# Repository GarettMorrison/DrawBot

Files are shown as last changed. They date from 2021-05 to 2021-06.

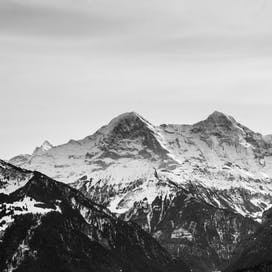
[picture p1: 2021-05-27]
DrawBoi_Dated/generateDrawfiles/Mountains.png

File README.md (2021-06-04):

### Code for large drawing robot

This is the WIP codebase for the DrawBot portion of my AI Art experiment. The target is to create an impressionist drawing of a target image on a canvas using procedural generation and robotics. 

Work in progress, SmallBoi.ino and controlSmallBoi.py have fully functional communication and can execute commands and scripts. DrawDXF.py converts dxf files to a list of commands readable by the controller script. 

SmallBoi is a simple stepper driven pulley system which, by controlling the length of two strings to a center mechanism, can move the head to any point on the surface. It also has a pair of servos on the head that can select one of four markers for printing. 

BigBoi consists of two DIY servos (referred to as bigServos) and a small hobby servo. Each bigServo is a DC motor driven by an L298N driver. It is connected via a gear (which gives a torque advantage) to a large spool, whos position is measured via potentiometer. These two spools connect to joints on a large (6ft tall) 2 axis arm, allowing control of the position of its head. The hobby servo control the pen on the head of the robot, by driving a spool which runs over pulleys, up through the arm, and around another spool which rotates the pen's angle. I used cheap DC motors, which are comically underpowered for the scale of the mechanism. I intend to add a pulley system to give ridiculously high mechanical advantage, which will be slow but able to draw without buying additional motors. 

Blog post in progress [here](https://www.garettmorrison.net/posts/in-progress/#drawbot)

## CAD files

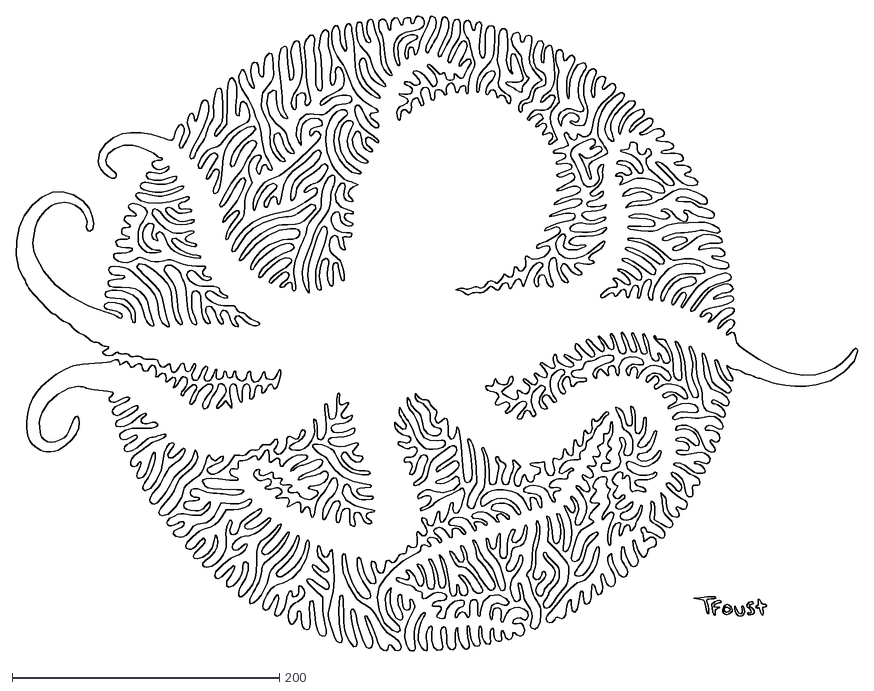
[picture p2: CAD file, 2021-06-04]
py/data/octopus.dxf
629.1 x 474.8

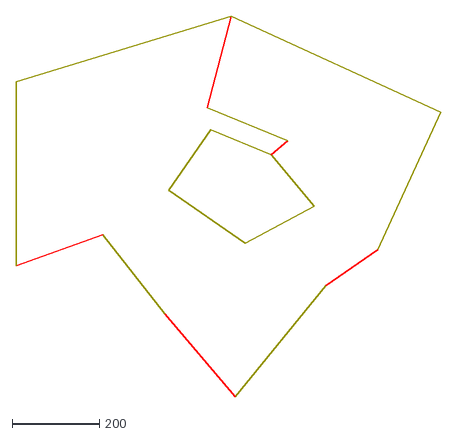
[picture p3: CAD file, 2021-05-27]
py/out/Drawing1.dxf
971.4 x 871.2

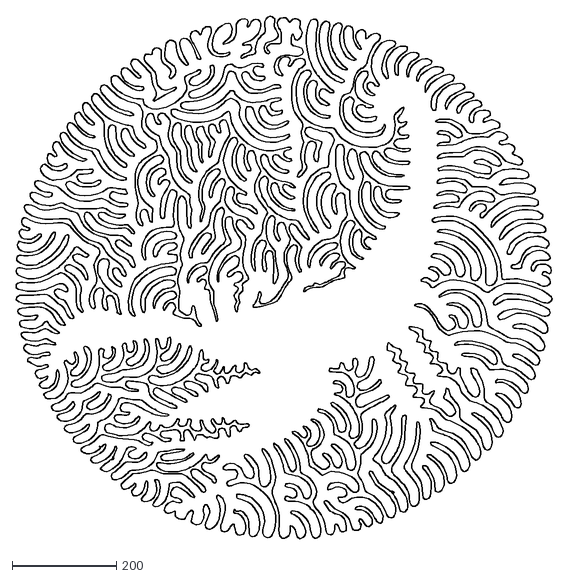
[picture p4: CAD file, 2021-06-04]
py/data/Scorp.dxf
1029.8 x 1003.4

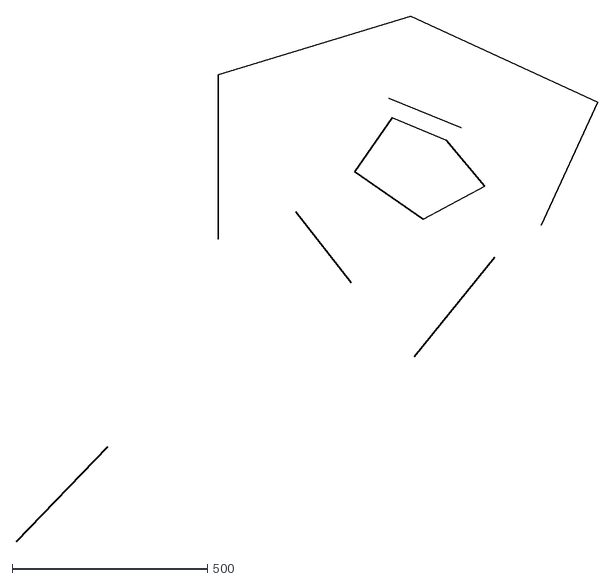
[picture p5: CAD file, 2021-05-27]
py/data/D1.dxf
1488.6 x 1344.6

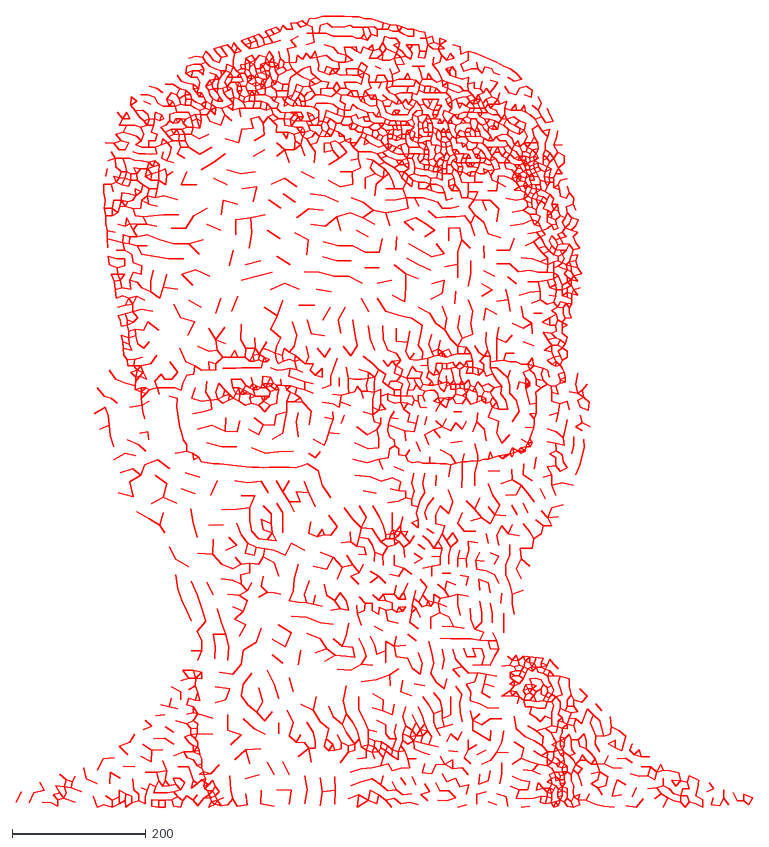
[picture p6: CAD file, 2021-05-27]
py/data/portrait.dxf
1103.0 x 1185.0

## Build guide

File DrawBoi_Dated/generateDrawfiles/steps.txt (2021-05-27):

0
0
0
0
0
0
0
0
0
0
0
0
0
0
0
0
0
0
0
0
0
0
0
0
0
0
0
0
0
0
0
0
0
0
0
0
0
0
0
0
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

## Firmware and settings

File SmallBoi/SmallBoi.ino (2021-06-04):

#include <Servo.h>
#include <math.h>
#include "miniStepper.h"

byte val; // variable to receive data from the serial port
int ledpin = 13; // Arduino LED pin 13 (on-board LED)

//Settings that can be changed in code, values are in 1/10"
int stepDelay = 7;
int stepDist = 52;
int lInit = 510;
int base = 455;
int lServoPos[] = {35, 135};  
int rServoPos[] = {125,45};
int imageScale = 60;
int lineXYDistStep = 20;
//Reference vals by pointer set
int *params[] = {&stepDelay, &stepDist, &lInit, &base, &lServoPos[0], &lServoPos[1], &rServoPos[0], &rServoPos[1], &imageScale, &lineXYDistStep};

float w0 = base/2;
float h0 = sqrt(pow(lInit, 2) - pow(base/2, 2));

byte command;
byte inBytes[10];

miniStepper left;
miniStepper right;

Servo lServo;
Servo rServo;


int twoByteInt(int MSB, int LSB){
   long int sum = (MSB*256 +LSB) -32767;
   if(sum > 32767){sum = 32767;}
   if(sum < -32767){sum = -32767;}
   return(sum);
}

float getDist(float x, float y){
   return(sqrt(pow(x, 2) + pow(y, 2)));
}

void getLR_fromXY(long int* outLR, float X, float Y){ //Converts XY raws into LR step positions
   float w = (X/32000)*imageScale + w0; //x position in dim + init width
   float h = (-1* Y/32000)*imageScale + h0; //y pos in dim + init h
   
   // Serial.println(X);
   // Serial.println(Y);
   // Serial.println('-');
   // Serial.println(w);
   // Serial.println(h);
   
   outLR[0] = floor((getDist(w      ,h) -lInit) *stepDist); //L position
   outLR[1] = floor((getDist(base -w,h) -lInit) *stepDist); //R position

   // Serial.println('-');
   // Serial.println(outLR[0]);
   // Serial.println(outLR[1]);
}

void getXY_fromLR(long int* outXY, float L, float R){
   float w = (pow(L/stepDist +lInit,2) - pow(R/stepDist +lInit,2) + pow(base,2)) / (2*base);
   float h = sqrt(pow(L/stepDist +lInit,2) - pow(w,2));

   outXY[0] = (w -w0) * (32000/imageScale);
   outXY[1] = (h -h0) * (32000/imageScale) *-1;

   // Serial.println('-');
   // Serial.println(w);
   // Serial.println(h);

   // Serial.println('-');
   // Serial.println(outXY[0]);
   // Serial.println(outXY[1]);
   // Serial.println("-----");
}

void moveR(int lTarget, int rTarget){
   bool doLoop = true;

   while(doLoop){
      int rPos = right.getPos();
      int lPos = left.getPos();

      if(lTarget == lPos && rTarget == rPos){
         doLoop = false;
         break;
      }

      if(lTarget < lPos){
         left.stepDown();
      }
      else if(lTarget > lPos){
         left.stepUp();
      }

      if(rTarget < rPos){
         right.stepDown();
      }
      else if(rTarget > rPos){
         right.stepUp();
      }

      delay(stepDelay);
   }
}



// void doLine(int xTarget, int yTarget){
//    //Get start of line from current pos
//    int startXY[2];
//    getXY_fromLR(startXY, left.getPos(), right.getPos());

//    //Calculated vals
//    int xDist = xTarget - startXY[0];
//    int yDist = yTarget - startXY[1];
//    float dist = getDist(xDist, yDist);
//    int pos = 0;

//    int targLR[2];

//    Serial.println("-");

//    Serial.print("Targs: ");
//    Serial.print(xTarget);
//    Serial.print(" | ");
//    Serial.println(yTarget);


//    Serial.print("StartPos: ");
//    Serial.print(startXY[0]);
//    Serial.print(" | ");
//    Serial.println(startXY[1]);



//    Serial.print("Dists: ");
//    Serial.print(dist);
//    Serial.print(" | ");
//    Serial.print(xDist);
//    Serial.print(" | ");
//    Serial.println(yDist);

//    while(true){
//       float frac = pos/dist;

//       //Break if after line
//       if(frac > 1){
//          break;
//       }

//       int xPos = frac*xDist +startXY[0];
//       int yPos = frac*yDist +startXY[1];

//       getLR_fromXY(targLR, xPos, yPos);

//       Serial.print(floor(frac*1000)); Serial.print(" | "); Serial.print(xPos); Serial.print(" | "); Serial.print(yPos);Serial.print(" | "); Serial.print(targLR[0]); Serial.print(" | "); Serial.println(targLR[1]);

//       moveR(targLR[0], targLR[1]); //Move to this pos



//       pos += lineXYDistStep; //Increment pos
//    }
// }



void setup() {
   Serial.begin(9600); // start serial communication at 9600bps

   left.attach(2,3,4,5);
   right.attach(7,8,11,12);

   lServo.attach(9);
   lServo.write(90);
   rServo.attach(10);
   rServo.write(90);

   pinMode(ledpin, OUTPUT); // pin 13 (on-board LED) as OUTPUT



   //---------------------------------------------------- Test functions

   // Serial.println("------");

   //    stepDelay = 1;
   //    int startXY[2];
   //    int targLR[2];
   //    getXY_fromLR(startXY, left.getPos(), right.getPos());

   //    int xTarget = -8767;
   //    int yTarget = -32767;

   //    //Calculated vals
   //    int xDiff = xTarget - startXY[0];
   //    int yDiff = yTarget - startXY[1];
   //    float dist = getDist(xDiff, yDiff);
   //    long int pos = lineXYDistStep;


   //    while(true){
   //       float frac = pos/dist;

   //       //Break if after line
   //       if(frac > 1){
   //          break;
   //       }

   //       int xPos = floor(frac*xDiff +startXY[0]);
   //       int yPos = floor(frac*yDiff +startXY[1]);

   //       getLR_fromXY(targLR, xPos, yPos);

   //       Serial.print(floor(frac*1000)); Serial.print(" |x: "); Serial.print(xPos); Serial.print(" |y: "); Serial.print(yPos); Serial.print(" |tx "); Serial.print(targLR[0]); Serial.print(" |ty "); Serial.println(targLR[1]);
   //       moveR(targLR[0], targLR[1]); //Move to this pos


   //       pos += lineXYDistStep; //Increment pos
   //    }


   // ---------------------------------------------------- End Test functions


}


void loop() {
   Serial.readBytes(& command, 1);

   //MoveRad
   if(command == 1){ 
      Serial.readBytes(inBytes, 4);
      long int lTarget = twoByteInt(inBytes[0], inBytes[1]); //Get int value, adjust to +/-
      long int rTarget = twoByteInt(inBytes[2], inBytes[3]); //Get int value, adjust to +/-

      // moveR(lTarget, rTarget); //Move to this pos
   }

   //AdjustRad
   else if(command == 2){ 
      Serial.readBytes(inBytes, 4);
      long int lTarget = left.getPos() + twoByteInt(inBytes[0], inBytes[1]); //Get int value, adjust to +/-
      long int rTarget = right.getPos() + twoByteInt(inBytes[2], inBytes[3]); //Get int value, adjust to +/-

      moveR(lTarget, rTarget); //Move to this pos
   }

   //Flash
   else if(command == 3){ 
      Serial.readBytes(inBytes, 1);
      for(int i = 0; i < int(inBytes[0]); i++){
         digitalWrite(ledpin, HIGH);
         delay(250);
         digitalWrite(ledpin, LOW);
         delay(250);
      }
   }

   //Pen
   else if(command == 5){ 
      Serial.readBytes(inBytes, 1);
      switch (inBytes[0]) {
          case 0: //All pens up
            lServo.write(90);
            rServo.write(90);
            break;
          case 1: //Pen 1 down
            lServo.write(lServoPos[0]);
            rServo.write(90);
            break;
          case 2: //Pen 2 down
            lServo.write(90);
            rServo.write(rServoPos[0]);
            break;
          case 3: //Pen 3 down
            lServo.write(lServoPos[1]);
            rServo.write(90);
            break;
          case 4: //Pen 4 down
            lServo.write(90);
            rServo.write(rServoPos[1]);
            break;
      }
   }

   //Move
   if(command == 7){ 
      Serial.readBytes(inBytes, 4);
      int xTarget = twoByteInt(inBytes[0], inBytes[1]); //Get int value, adjust to +/-
      int yTarget = twoByteInt(inBytes[2], inBytes[3]); //Get int value, adjust to +/-

      long int targsLR[2];//Convert to LR
      getLR_fromXY(targsLR, xTarget, yTarget);

      moveR(targsLR[0], targsLR[1]); //Move to this pos
   }

   //Adjust
   else if(command == 8){ 
      Serial.readBytes(inBytes, 4);
      int xTarget = twoByteInt(inBytes[0], inBytes[1]); //Get int value, adjust to +/-
      int yTarget = twoByteInt(inBytes[2], inBytes[3]); //Get int value, adjust to +/-

      long int targsLR[2]; //Convert to LR
      getLR_fromXY(targsLR, xTarget, yTarget);
      targsLR[0] += left.getPos(); //Add inits, to make adjust
      targsLR[1] += right.getPos();

      moveR(targsLR[0], targsLR[1]); //Move to this pos
   }

   //Line
   else if(command == 10){
      Serial.readBytes(inBytes, 4);
      int xTarget = twoByteInt(inBytes[0], inBytes[1]); //Get int value, adjust to +/-
      int yTarget = twoByteInt(inBytes[2], inBytes[3]); //Get int value, adjust to +/-


      //Get start of line from current pos
      long int startXY[2];
      long int targLR[2];

      getXY_fromLR(startXY, left.getPos(), right.getPos());

      //Calculated vals
      long int xDiff = xTarget - startXY[0];
      long int yDiff = yTarget - startXY[1];
      float dist = getDist(xDiff, yDiff);
      long int pos = lineXYDistStep;


      while(true){
         float frac = pos/dist;

         //Break if after line
         if(frac > 1){
            break;
         }

         int xPos = floor(frac*xDiff +startXY[0]);
         int yPos = floor(frac*yDiff +startXY[1]);

         getLR_fromXY(targLR, xPos, yPos);

         moveR(targLR[0], targLR[1]); //Move to this pos

         pos += lineXYDistStep; //Increment pos
      }
   }


   //setVal
   else if(command == 9){ 
      Serial.readBytes(inBytes, 3);
      int var = inBytes[0]; //Get selected variable
      int val = twoByteInt(inBytes[1], inBytes[2]); //Get int value to set to

      *params[var] = val;

      w0 = base/2;
      h0 = sqrt(pow(lInit, 2) - pow(base/2, 2));
   }


   if(command != 0){
      Serial.write(command);
   }
   command = 0;

   delay(10);
}

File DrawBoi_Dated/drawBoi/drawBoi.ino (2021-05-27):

#include "steps.h"
// #include <Servo.h>

static int delayTime = 3;
static int stepsPerMove = 4;

class drawServo{
	public:
		drawServo(int pin);
		void penUp();
		void penDown();
	private:
		// bool isPenDown;
		// int thisServo;
		int pin;
};

drawServo::drawServo(int inPin){
	pin = inPin;
	pinMode(pin, OUTPUT);
	// thisServo.attach(pin);
	// thisServo.write(90);
	// isPenDown = false;
}

void drawServo::penUp(){
	analogWrite(pin, 180);
	// thisServo.write(90);
}
void drawServo::penDown(){
	analogWrite(pin, 200);
	// thisServo.write(180);
}


class stepper{
	public:
		// stepper();
		stepper(int A, int B, int C, int D);
		void stepCCW();
		void stepCW();
		void disable();
		long int getStep();

	private:
		int aPin;
		int bPin;
		int cPin;
		int dPin;
		int stepPos;
		long int stepCount;
};

stepper::stepper(int A, int B, int C, int D){
	aPin = A;
	bPin = B;
	cPin = C;
	dPin = D;

	pinMode(aPin, OUTPUT);
	pinMode(bPin, OUTPUT);
	pinMode(cPin, OUTPUT);
	pinMode(dPin, OUTPUT);

	stepPos = 0;
	stepCount = 0;

	digitalWrite(aPin, HIGH);
	digitalWrite(bPin, LOW);
	digitalWrite(cPin, LOW);
	digitalWrite(dPin, LOW);
}

// stepper::stepper(){
// 	aPin = -1;
// 	bPin = -1;
// 	cPin = -1;
// 	dPin = -1;
// 	stepPos = 0;
// 	stepCount = 0;
// }

void stepper::stepCCW(){
	if(stepPos == 0){
		digitalWrite(aPin, LOW);
		digitalWrite(bPin, HIGH);
		digitalWrite(cPin, LOW);
		digitalWrite(dPin, LOW);

		stepPos = 1;
	}
	else if(stepPos == 1){
		digitalWrite(aPin, LOW);
		digitalWrite(bPin, LOW);
		digitalWrite(cPin, HIGH);
		digitalWrite(dPin, LOW);

		stepPos = 2;
	}
	else if(stepPos == 2){
		digitalWrite(aPin, LOW);
		digitalWrite(bPin, LOW);
		digitalWrite(cPin, LOW);
		digitalWrite(dPin, HIGH);

		stepPos = 3;
	}
	else if(stepPos == 3){
		digitalWrite(aPin, HIGH);
		digitalWrite(bPin, LOW);
		digitalWrite(cPin, LOW);
		digitalWrite(dPin, LOW);

		stepPos = 0;
	}

	stepCount++;
	delay(delayTime);
}

void stepper::stepCW(){
	if(stepPos == 2){
		digitalWrite(aPin, LOW);
		digitalWrite(bPin, HIGH);
		digitalWrite(cPin, LOW);
		digitalWrite(dPin, LOW);

		stepPos = 1;
	}
	else if(stepPos == 3){
		digitalWrite(aPin, LOW);
		digitalWrite(bPin, LOW);
		digitalWrite(cPin, HIGH);
		digitalWrite(dPin, LOW);

		stepPos = 2;
	}
	else if(stepPos == 0){
		digitalWrite(aPin, LOW);
		digitalWrite(bPin, LOW);
		digitalWrite(cPin, LOW);
		digitalWrite(dPin, HIGH);

		stepPos = 3;
	}
	else if(stepPos == 1){
		digitalWrite(aPin, HIGH);
		digitalWrite(bPin, LOW);
		digitalWrite(cPin, LOW);
		digitalWrite(dPin, LOW);

		stepPos = 0;
	}

	stepCount--;
	delay(delayTime);
}

void stepper::disable(){
	digitalWrite(aPin, LOW);
	digitalWrite(bPin, LOW);
	digitalWrite(cPin, LOW);
	digitalWrite(dPin, LOW);
}

long int stepper::getStep(){
	return(stepCount);
}



//Declare our two steppers
stepper left(30,32,34,36);
stepper right(38,40,42,44);
drawServo draw(4);


/*
left 
CCW = down
CW = up

right
CCW = up
cw = down
*/

void runStep(bool pen, bool S0, bool S1, bool S2){
	switch(pen){
		case true:
			draw.penDown();
			//Make servo go down
			break;
		case false:
			draw.penUp();
			//make servo go up
			break;
	}

	/*
	cases
	^^ 7
	vv 6
	^v 5
	v^ 4
	^- 3
	v- 2
	-^ 1
	-v 0
	*/

	int stepperMove = S0*4 + S1*2 + S2;
	// Serial.println(stepperMove);
	for(int i = 0; i < stepsPerMove; i++){
		switch(stepperMove){
		case 0:
			left.stepCW();
			right.stepCCW();
			break;
		case 1:
			left.stepCCW();
			right.stepCW();
			break;
		case 2:
			left.stepCW();
			right.stepCW();
			break;
		case 3:
			left.stepCCW();
			right.stepCCW();
			break;
		case 4:
			left.stepCW();
			break;
		case 5:
			left.stepCCW();
			break;
		case 6:
			right.stepCCW();
			break;
		case 7:
			right.stepCW();
			break;

		}
	}
}

void setup(){
	pinMode(LED_BUILTIN, OUTPUT);
	pinMode(3, INPUT_PULLUP);
	pinMode(2, INPUT_PULLUP);

	Serial.begin(9600);
	Serial.println("BOOTED");

	right.disable();
	left.disable();

	bool startTests[3] = {false, false, false};
	while(1 == 1){
		draw.penDown();

		startTests[0] = digitalRead(3);
		startTests[1] = digitalRead(3);
		startTests[2] = digitalRead(3);

		// Serial.println(startTests[0]);

		if(startTests[0] && startTests[1] && startTests[2]){
			break;
		}
	}

	while(1 == 1){
		draw.penUp();

		startTests[0] = digitalRead(2);
		startTests[1] = digitalRead(2);
		startTests[2] = digitalRead(2);

		// Serial.println(startTests[0]);

		if(startTests[0] && startTests[1] && startTests[2]){
			break;
		}
	}


	Serial.println("STARTING");

	for(int i = 0; i < stepCount; i++){
		byte spliceByte = pgm_read_byte_near(steps + i);
		// Serial.println(spliceByte);
		//Split byte into stepBoolss
		bool stepBoolsA[4] = {false,false,false,false};
		bool stepBoolsB[4] = {false,false,false,false};


		if(spliceByte > 127){ //Pen = 1
			spliceByte -= 128;
			stepBoolsA[0] = true;
		}
		if(spliceByte > 63){ //S0 = 1
			spliceByte -= 64;
			stepBoolsA[1] = true;
		}
		if(spliceByte > 31){ //S1 = 1
			spliceByte -= 32;
			stepBoolsA[2] = true;
		}
		if(spliceByte > 15){ //S2 = 1
			spliceByte -= 16;
			stepBoolsA[3] = true;
		}

		if(spliceByte > 7){ //Pen = 1
			spliceByte -= 8;
			stepBoolsB[0] = true;
		}
		if(spliceByte > 3){ //S0 = 1
			spliceByte -= 4;
			stepBoolsB[1] = true;
		}
		if(spliceByte > 1){ //S1 = 1
			spliceByte -= 2;
			stepBoolsB[2] = true;
		}
		if(spliceByte > 0){ //S2 = 1
			stepBoolsB[3] = true;
		}

		runStep(stepBoolsA[0], stepBoolsA[1], stepBoolsA[2], stepBoolsA[3]);
		runStep(stepBoolsB[0], stepBoolsB[1], stepBoolsB[2], stepBoolsB[3]);
	}

	// for(int i = 0; i < 200; i++){
	// 	right.stepCCW();
	// }

	// for(int i = 0; i < 200; i++){
	// 	right.stepCW();
	// }

	Serial.println("Returning");

	int lStep = left.getStep();
	int rStep = right.getStep();
	do{
		lStep = left.getStep();
		rStep = right.getStep();
		if(left.getStep() < 0){left.stepCCW();}
		else if(left.getStep() > 0){left.stepCW();}

		if(right.getStep() < 0){right.stepCCW();}
		else if(right.getStep() > 0){right.stepCW();}
		Serial.println(lStep);
	}while(lStep != 0 && rStep != 0);

	draw.penUp();
	right.disable();
	left.disable();
	Serial.println("Finished");
}

void loop() {
	Serial.println("DONE!");
	digitalWrite(LED_BUILTIN, HIGH);
	// draw.penDown();
	delay(5000);
	digitalWrite(LED_BUILTIN, LOW);
	// draw.penUp();
	delay(5000);
}

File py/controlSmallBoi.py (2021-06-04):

import serial
import sys


def bigLoop(port, inStr, nestCount):
	indt = "" #Set indent
	for i in range(nestCount): indt += "   "

	if inStr != "":
		try:
			fileIn = open(inStr, "r")
		except:
			print(indt + "File Not Found")
			return(0)

	while True:
		

		if inStr != "":
			command = fileIn.readline()
			if command == "":
				break
		else:
			command = input("Input command: ") # "m -99 500" #
			if command == "":
				continue


		command = command.split()

		sendBytes = (b'\x00') #Default val is 0



		#Skip comments
		if command[0] in ("#"):
			continue


		#moveRad Command
		elif command[0] in ("moveRad", "mr"):	
			if len(command) < 3:
				print(indt + "Too few inputs")
				continue
			comm = (1).to_bytes(1, "big") # val is 1
			L = (int(command[1]) +32767).to_bytes(2, "big") #Get l position target
			R = (int(command[2]) +32767).to_bytes(2, "big") #Get l position target


			print(indt + "Moving to L:" + command[1] + " R:" + command[2])

			sendBytes = comm + L + R

		#Adjust Command
		elif command[0] in ("adjustRad", "ar"):
			if len(command) < 3:
				print(indt + "Too few inputs")
				continue
			comm = (2).to_bytes(1, "big") #Val is 2
			L = (int(command[1]) +32767).to_bytes(2, "big") #Get l position target
			R = (int(command[2]) +32767).to_bytes(2, "big") #Get l position target


			print(indt + "Adjusting by L:" + command[1] + " R:" + command[2])

			sendBytes = comm + R + L

		#Flash command
		elif command[0] in ("flash", "f"):
			if len(command) < 2:
				print(indt + "Too few inputs")
				continue
			comm = (3).to_bytes(1, "big") #Val is 3
			count = int(command[1]).to_bytes(1, "big")
			print(indt + "Flashing LED " + command[1] + " times")

			sendBytes = comm + count

		#Pen command 5
		elif command[0] in ("pen", "p"):
			if len(command) < 1:
				print(indt + "Too few inputs")
				continue
			comm = (5).to_bytes(1, "big") #Val is 3
			var = int(command[1]).to_bytes(1, "big")

			outStr = "Setting Pen to " + str(var)

			print(indt + outStr)

			sendBytes = comm + var

		#Wait command 6
		elif command[0] in ("wait", "w"):
			outStr = ""
			for i in command[1:]:
				outStr += i + " "

			print(indt + outStr)
			input(indt + "Press Enter:")
			continue

		#move 7
		elif command[0] in ("move", "m"):	
			if len(command) < 3:
				print(indt + "Too few inputs")
				continue
			comm = (7).to_bytes(1, "big") # val is 1
			X = (int(command[1]) +32767).to_bytes(2, "big") #Get position target
			Y = (int(command[2]) +32767).to_bytes(2, "big") #Get position target

			print(indt + "Moving to X:" + command[1] + " Y:" + command[2])

			sendBytes = comm + X + Y


		#adjust 8
		elif command[0] in ("adjust", "a"):
			if len(command) < 3:
				print(indt + "Too few inputs")
				continue
			comm = (8).to_bytes(1, "big") #Val is 2
			X = (int(command[1]) +32767).to_bytes(2, "big") #Get position target
			Y = (int(command[2]) +32767).to_bytes(2, "big") #Get position target

			print(indt + "Adjusting by X:" + command[1] + " Y:" + command[2])

			sendBytes = comm + X + Y


		#setVal 9
		elif command[0] in ("setVal", "s"):
			if len(command) < 3:
				print(indt + "Too few inputs")
				continue
			comm = (9).to_bytes(1, "big") #Val is 2
			var = (int(command[1])).to_bytes(1, "big") #Get var to change
			val = (int(command[2]) +32767).to_bytes(2, "big") #Get value to set var to

			print(indt + "Setting " + command[1] + " to " + command[2])

			sendBytes = comm + var + val


		#line 10
		elif command[0] in ("line", "l"):	
			if len(command) < 3:
				print(indt + "Too few inputs")
				continue
			comm = (10).to_bytes(1, "big") # val is 1
			X = (int(command[1]) +32767).to_bytes(2, "big") #Get position target
			Y = (int(command[2]) +32767).to_bytes(2, "big") #Get position target

			print(indt + "Drawing line to to X:" + command[1] + " Y:" + command[2])

			sendBytes = comm + X + Y


		#execute command 11
		elif command[0] in ("execute", "x"):
			if len(command) < 1:
				print(indt + "Too few inputs")
				continue
			fileStr = command[1]
			bigLoop(port, fileStr, nestCount+1)
			continue

		#Break command 12
		elif command[0] in ("break", "b"):
			print(indt + "Exiting!")
			sys.exit()

		#Display command 13
		elif command[0] in ("display", "d"):
			outStr = ""
			for i in command[1:]:
				outStr += i + " "
			print(indt + outStr)
			continue

		#Ignore comment
		elif command[0] == ("#"):
			continue

		else:
			print(indt + "Unknown Command")
			continue

		port.write(sendBytes)

		returnCode = int.from_bytes(port.read(1), "big")

		print(indt + "Returned: " + str(returnCode))



#Basically just call loop

initPort = serial.Serial('/dev/ttyS16', baudrate=9600, timeout= None)

initStr = ""
if len(sys.argv) > 1:
	initStr = sys.argv[1]

bigLoop(initPort, initStr, 0)

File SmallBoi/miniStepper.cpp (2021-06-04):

/*
	miniStepper.h
	Simple Stepper Library
	Made by Garett Morrison
*/

#include "Arduino.h"
#include "miniStepper.h"

miniStepper::attach(int _a, int _b, int _c, int _d){
	pos = 0;
	step = 0;

	a = _a;
	b = _b;
	c = _c;
	d = _d;

	pinMode(a, OUTPUT);
	pinMode(b, OUTPUT);
	pinMode(c, OUTPUT);
	pinMode(d, OUTPUT);

	digitalWrite(a, HIGH);
	digitalWrite(b, LOW);
	digitalWrite(c, LOW);
	digitalWrite(d, LOW);
}

miniStepper::stepUp(){
	if(step == 0){
		step = 1;
		digitalWrite(b, HIGH);
		digitalWrite(a, LOW);
	}
	else if(step == 1){
		step = 2;
		digitalWrite(c, HIGH);
		digitalWrite(b, LOW);
	}
	else if(step == 2){
		step = 3;
		digitalWrite(d, HIGH);
		digitalWrite(c, LOW);
	}
	else if(step == 3){
		step = 0;
		digitalWrite(a, HIGH);
		digitalWrite(d, LOW);
	}

	pos += 1;
}

miniStepper::stepDown(){
	if(step == 0){
		step = 3;
		digitalWrite(d, HIGH);
		digitalWrite(a, LOW);
	}
	else if(step == 1){
		step = 0;
		digitalWrite(a, HIGH);
		digitalWrite(b, LOW);
	}
	else if(step == 2){
		step = 1;
		digitalWrite(b, HIGH);
		digitalWrite(c, LOW);
	}
	else if(step == 3){
		step = 2;
		digitalWrite(c, HIGH);
		digitalWrite(d, LOW);
	}

	pos -= 1;
}

long int miniStepper::getPos(){
	return(pos);
}

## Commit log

2021-05-27 Realized I should backup the py gen scripts, converters, gui, and smallboi scripts
    [D1.dxf, Drawing1.dxf, mr.dxf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]
2021-06-02 LINE COMMAND WORKS FULLY OPERATIONAL
    [D1.dxf, D1_Processed.dxf, mr.dxf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]
2021-06-02 fixed for tall files
    [D1.dxf, D1_Processed.dxf, portrait_draw.dxf]
2021-06-04 Fixed integer overflow issue, Line is fully operational
    [Scorp.dxf, Spir.dxf, octopus.dxf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]
2021-06-04 Removed excess files
    [Spir.dxf, octopus_draw.dxf, spir2.dxf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]
